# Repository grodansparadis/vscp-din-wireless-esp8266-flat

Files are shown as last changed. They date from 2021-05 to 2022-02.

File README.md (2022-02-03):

# vscp-din-wireless-esp8266-flat
ESP8266 based VSCP controller in flat DIN package. The usage for the modul is to interface a P1 electricity meter and report meter readings over VSCP.

Can be powered from the meter or externally.

**Note!** This is still a prototype.

## PCB's
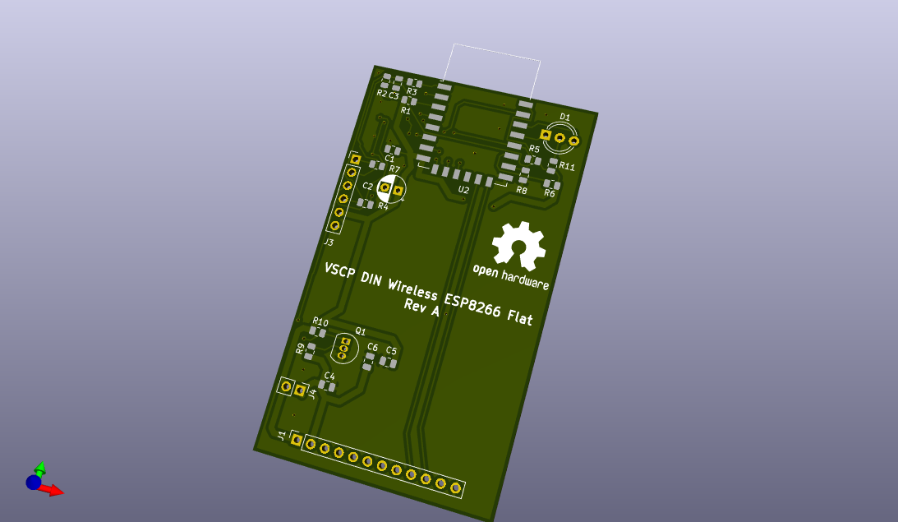
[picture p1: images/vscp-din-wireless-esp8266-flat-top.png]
Control Interface Top


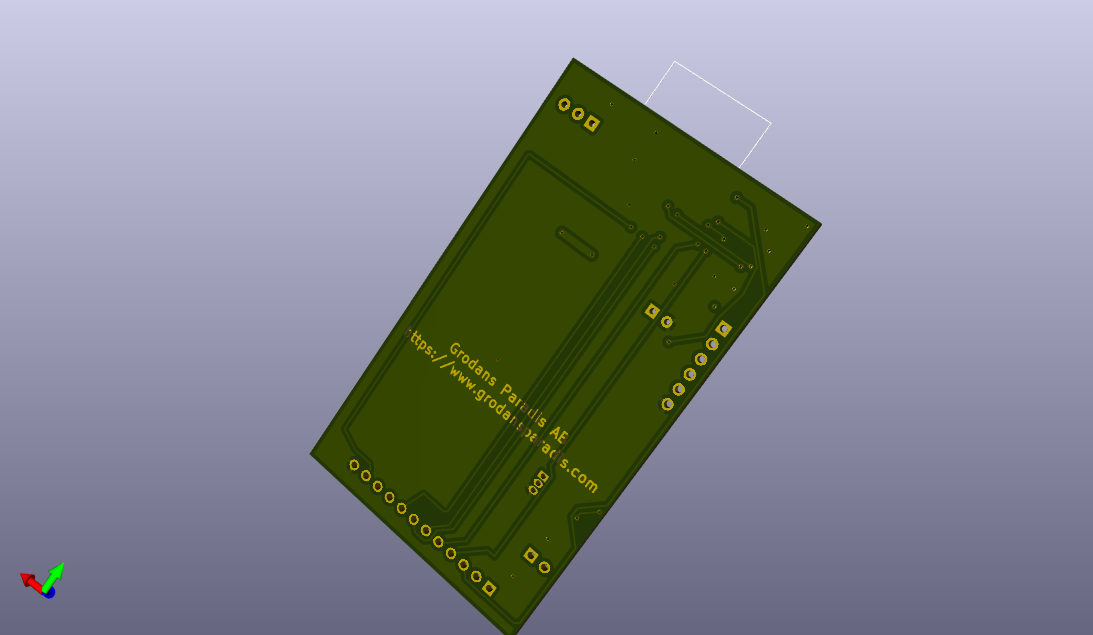
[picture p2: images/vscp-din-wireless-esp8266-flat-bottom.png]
Control Interface Bottom
 

---

Part of the [VSCP Project](https://www.vscp.org).

Copyright 2021-2022 © Åke Hedman, (Grodans Paradis AB)[https://www.grodansparadis.com]

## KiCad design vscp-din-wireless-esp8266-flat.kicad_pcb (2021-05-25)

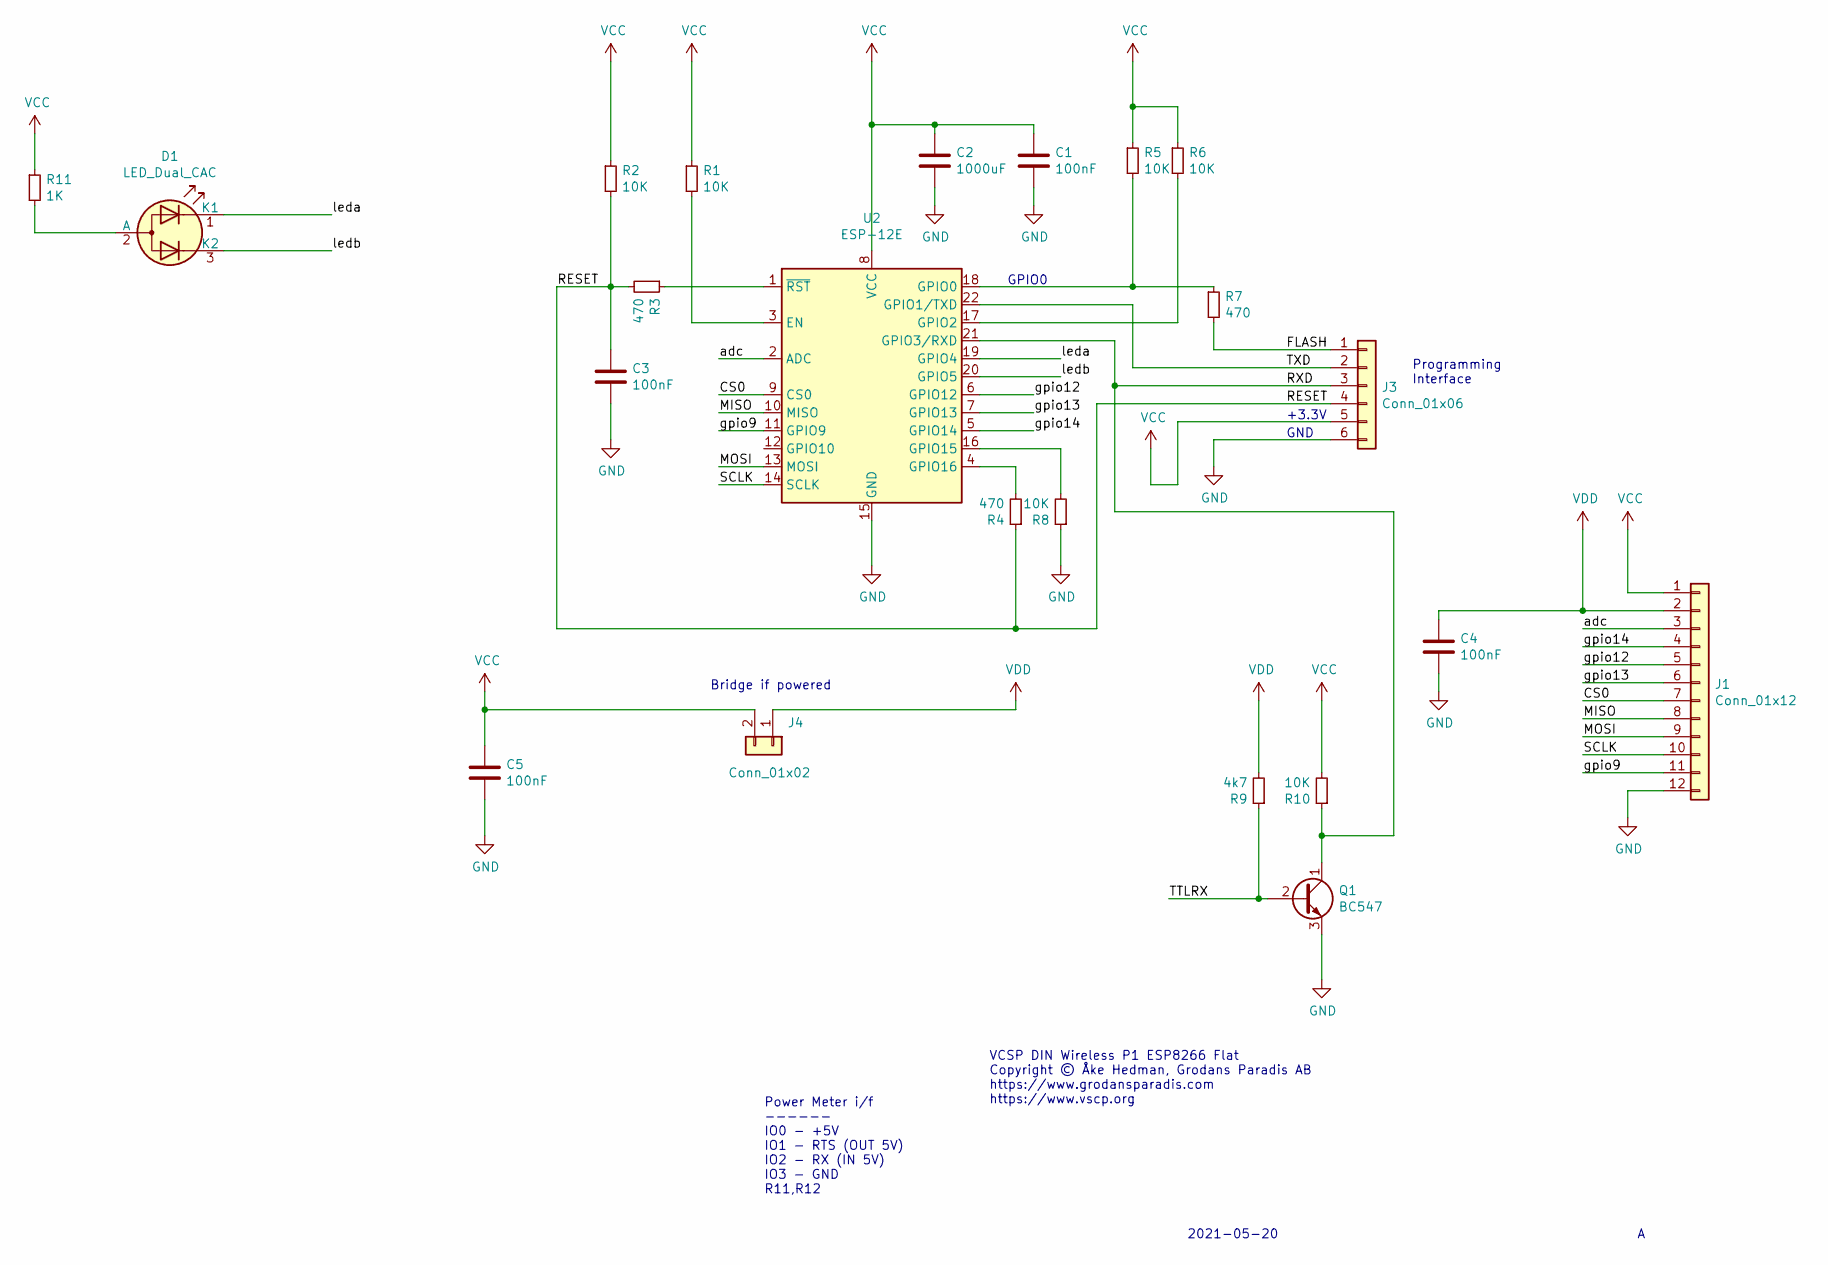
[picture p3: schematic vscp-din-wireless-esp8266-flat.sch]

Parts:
C1, C3, C4, C5: 100nF; C_0805_2012Metric
C2: 1000uF; CP_Radial_D5.0mm_P2.50mm
D1: LED_Dual_CAC; LED_D5.0mm-3
J1: Conn_01x12; PinSocket_1x12_P2.54mm_Vertical
J3: Conn_01x06; PinHeader_1x06_P2.54mm_Vertical
J4: Conn_01x02; PinHeader_1x02_P2.54mm_Vertical
Q1: BC547; TO-92_Inline
R1, R2, R5, R6, R8, R10: 10K; R_0805_2012Metric
R3, R7: 470; R_0805_2012Metric
R4: 470; C_0805_2012Metric
R9: 4k7; R_0805_2012Metric
R11: 1K; R_0805_2012Metric
U2: ESP-12E

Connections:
/CS0: J1.7, U2.9 (CS0)
/FLASH: J3.1, R7.2
/MISO: J1.8, U2.10 (MISO)
/MOSI: J1.9, U2.13 (MOSI)
/RESET: C3.1, J3.4, R2.2, R3.2, R4.1
/RXD: J3.3, Q1.1 (C), R10.1, U2.21 (GPIO3/RXD)
/SCLK: J1.10, U2.14 (SCLK)
/TTLRX: Q1.2 (B), R9.1
/TXD: J3.2, U2.22 (GPIO1/TXD)
/adc: J1.3, U2.2 (ADC)
/gpio9: J1.11, U2.11 (GPIO9)
/gpio12: J1.5, U2.6 (GPIO12)
/gpio13: J1.6, U2.7 (GPIO13)
/gpio14: J1.4, U2.5 (GPIO14)
/leda: D1.1 (K1), U2.19 (GPIO4)
/ledb: D1.3 (K2), U2.20 (GPIO5)
GND: C1.2, C2.2, C3.2, C4.2, C5.2, J1.12, J3.6, Q1.3 (E), R8.1, U2.15 (GND); also elsewhere on the board
unnamed: D1.2 (A), R11.2
unnamed: R1.2, U2.3 (EN)
unnamed: R3.1, U2.1 (~RST)
unnamed: R4.2, U2.4 (GPIO16)
unnamed: R5.2, R7.1, U2.18 (GPIO0)
unnamed: R6.2, U2.17 (GPIO2)
unnamed: R8.2, U2.16 (GPIO15)
VCC: C1.1, C2.1, C5.1, J1.1, J3.5, J4.2, R1.1, R2.1, R5.1, R6.1, R10.2, R11.1, U2.8 (VCC)
VDD: C4.1, J1.2, J4.1, R9.2; also elsewhere on the board

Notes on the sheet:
VCSP DIN Wireless P1 ESP8266 Flat Copyright © Åke Hedman, Grodans Paradis AB https://www.grodansparadis.com https://www.vscp.org
2021-05-20
GND
Programming Interface
+3.3V
Power Meter i/f ------ IO0 - +5V IO1 - RTS (OUT 5V) IO2 - RX (IN 5V) IO3 - GND R11,R12
GPIO0
Bridge if powered

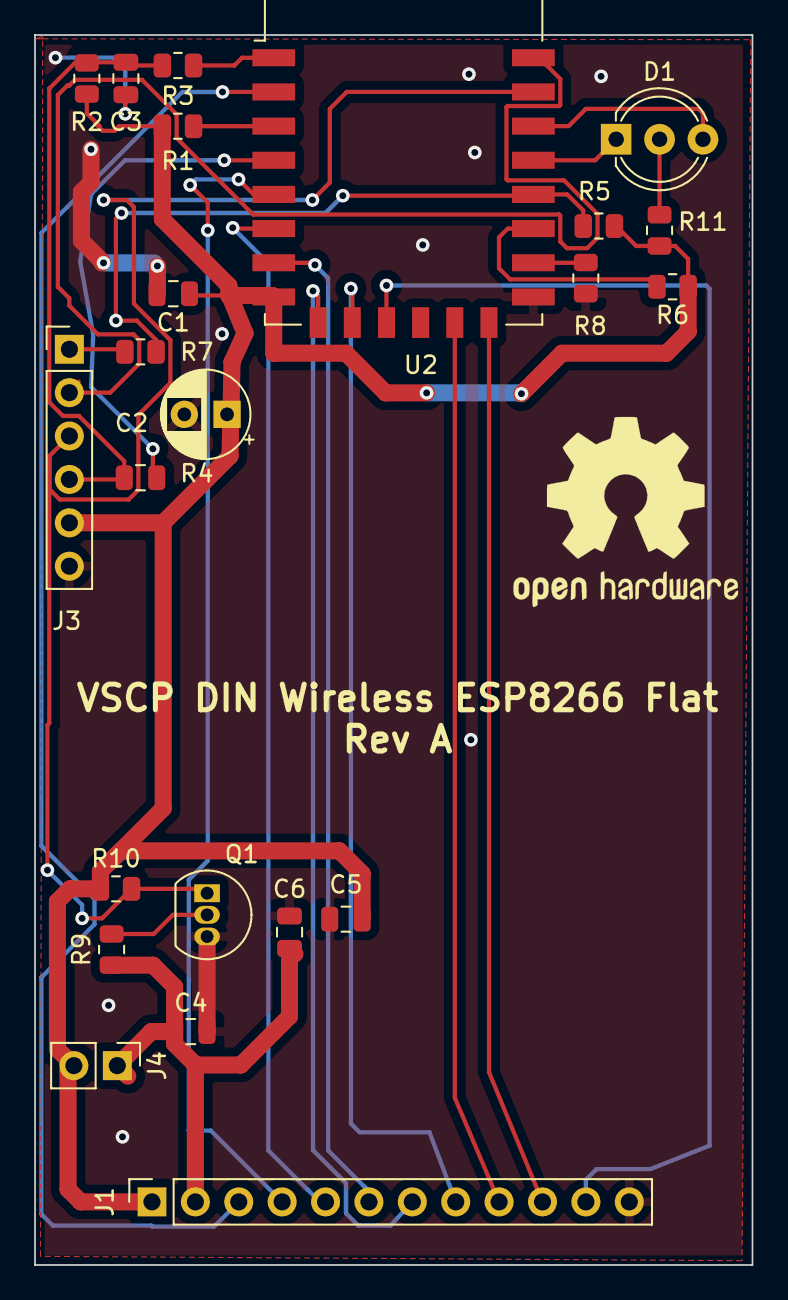
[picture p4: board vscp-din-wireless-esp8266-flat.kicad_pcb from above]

Board: 2 copper layers, 42.0 x 72.0 mm, 23 parts (0 on the bottom side), 26 nets.

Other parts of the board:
C6: 100nF; C_0805_2012Metric

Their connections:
GND: C6.2; also elsewhere on the board
VDD: C6.1; also elsewhere on the board

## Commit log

2021-05-24 Initial import
    [_vscp-din-wireless-esp8266-flat.kicad_pcb, vscp-din-wireless-esp8266-flat.kicad_pcb, vscp-din-wireless-esp8266-flat.sch]
2021-05-25 Removed obsolite file
    [_vscp-din-wireless-esp8266-flat.kicad_pcb]
2021-05-25 Added gerbers
    [vscp-din-wireless-esp8266-flat-B_Cu.gbr, vscp-din-wireless-esp8266-flat-B_Mask.gbr, vscp-din-wireless-esp8266-flat-B_Paste.gbr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]
